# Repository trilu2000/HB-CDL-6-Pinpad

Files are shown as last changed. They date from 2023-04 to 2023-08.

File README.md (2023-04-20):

# HB-CDL-6-Pinpad
ein Pinpad zur Einbindung in Homematic

Im Gegensatz zum HB-CDL-6 (https://github.com/trilu2000/HB-CDL-6) mit Touchscreen habe ich diesmal versucht nur Standardbauteile zu verwenden um einen einfachen Nachbau zu gewährleisten.
Herausgekommen ist dabei das HB-CDL-6-Pinpad.

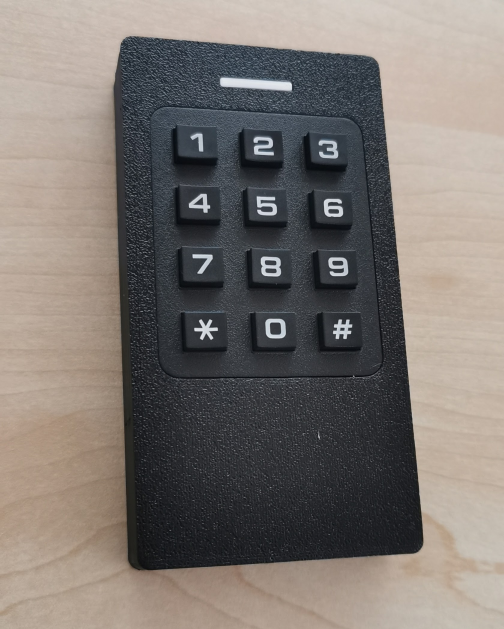
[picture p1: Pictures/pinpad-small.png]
Gerätebild


Grundsätzlich verhält sich das Gerät wie ein 6 Fach Wandtaster, nur das die Tasten durch einen Pincode ersetzt werden.
Über die CCU Oberfläche hat man die Möglichkeit 12 verschedene Pin's den jeweiligen Kanälen zuzuordnen.

Selbst das Anlernen des Geräts wird über die Pin-Tastatur gestartet.

## Bauteile für den Nachbau
* HMSensor-CR2032 ohne CR2032 Batteriehalter https://asksinpp.de/Projekte/psi/HMSensor/#hmsensor-cr2032
* 3x4 Keypad https://www.ebay.de/itm/322734499078
* Batteriefedern https://www.ebay.de/itm/134133246378
* Batterie Federplatte https://www.ebay.de/itm/134128858997
* Gedruckte Gehäuseteile (im STL Unterordner) 

## Funktionsweise
Das Gerät hat 6 Schaltkanäle und kann 12 Pins verwalten. Die Einzelnen Pins können einem oder mehreren Kanälen zugeordnet werden.
Die Pineingabe folgt diesem Muster:
```
<Kanal> * <PIN> #
```

Kanal kann 1 bis 6 sein, es lassen sich im Programmcode aber auch Sonderkanäle für diverse Aktionen einbauen.
Derzeit gibt es nur einen Sonderkanal:
```
20 * Master PIN # startet das Pairing.
```

Die PIN's können bis zu 8 Stellen lang sein. Es besteht auch die Möglichkeit Kanäle einem leeren PIN zuzuweisen.
Eine mögliche Anwendung wäre das Schliessen der Garage.
Dazu würde man dann folgendes Muster eintippen:
```
<Kanal> * #
<Kanal> #
```
  
Pin 0 ist definiert als Master PIN. Dieser PIN ist im Programmcode definiert als: 
```
const uint8_t master_pwd[9] = { 0xff,'1','2','3','4','5','6','7','8', };
```
Der Master PIN kann beim kompilieren oder später über die CCU Oberfläche geändert werden.

Da es sich um ein Homebrew Gerät handelt, braucht es Jérôme's addon zur Einbindung in die CCU.

 https://github.com/jp112sdl/JP-HB-Devices-addon

## Pinpad

Es gibt verschiedene Versionen des Pinpads mit unterschiedlichen Pinbelegungen.

 Das von mir verwendete hat folgendes Pinout:

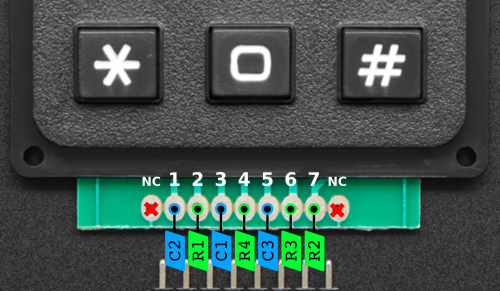
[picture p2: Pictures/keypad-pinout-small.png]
Keypad Pinout


Im Programmcode werden die Pins den Eingängen der HM Sensor Platine zugewiesen:
```
#define C2_PIN A0
#define R1_PIN A1
#define C1_PIN A2
#define R4_PIN A3
#define C3_PIN A4
#define R3_PIN A5
#define R2_PIN 3
```

## Bilder zum Aufbau

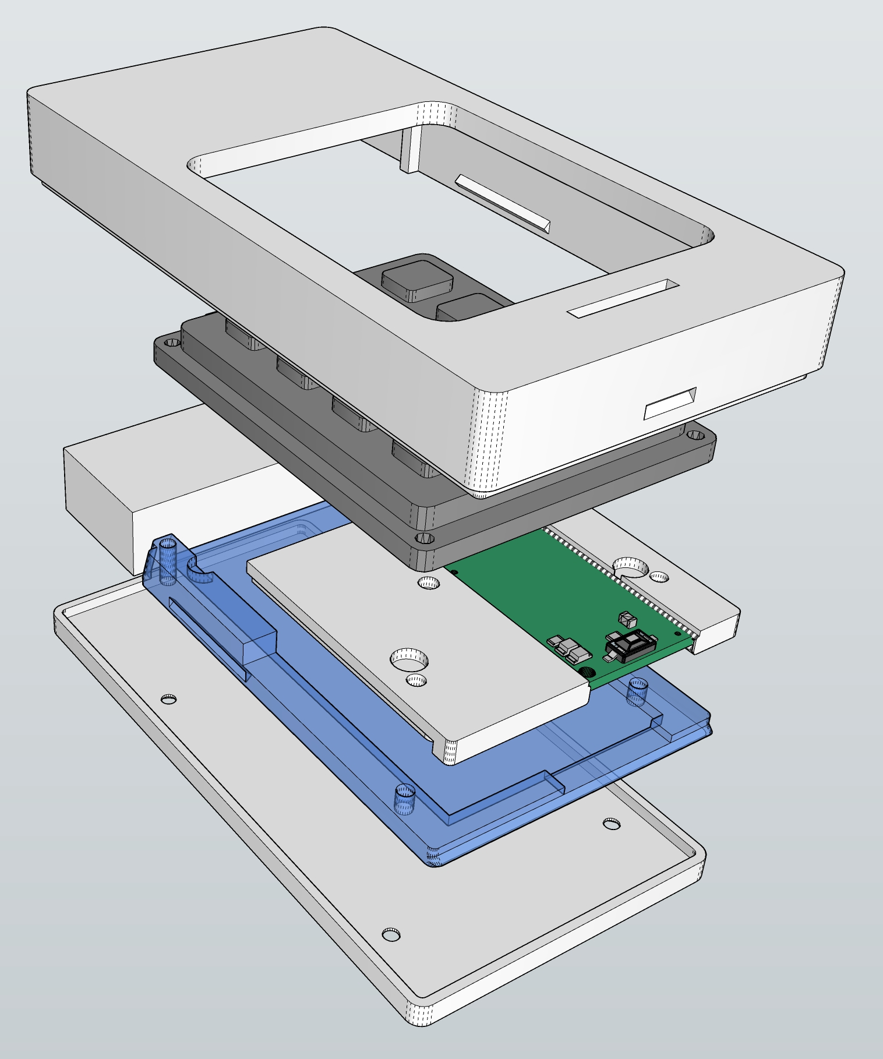
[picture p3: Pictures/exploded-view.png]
Pinpad exploded view


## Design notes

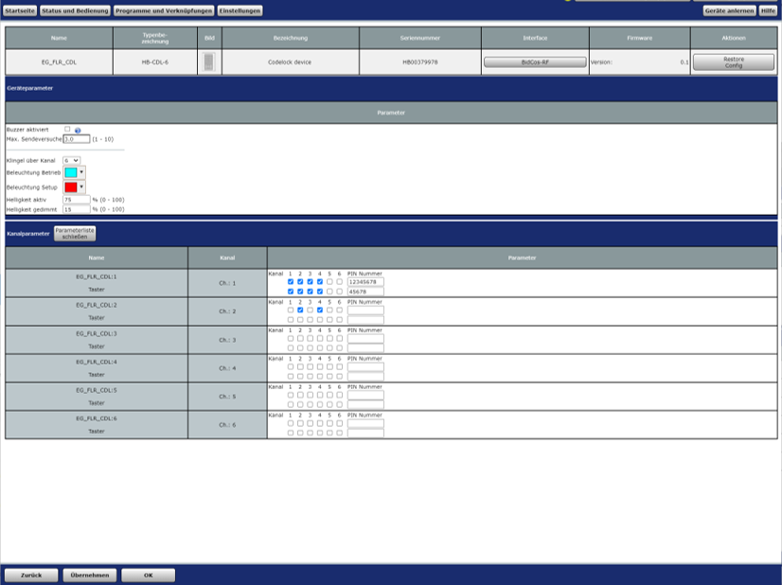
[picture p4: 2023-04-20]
Pictures/CCU.png

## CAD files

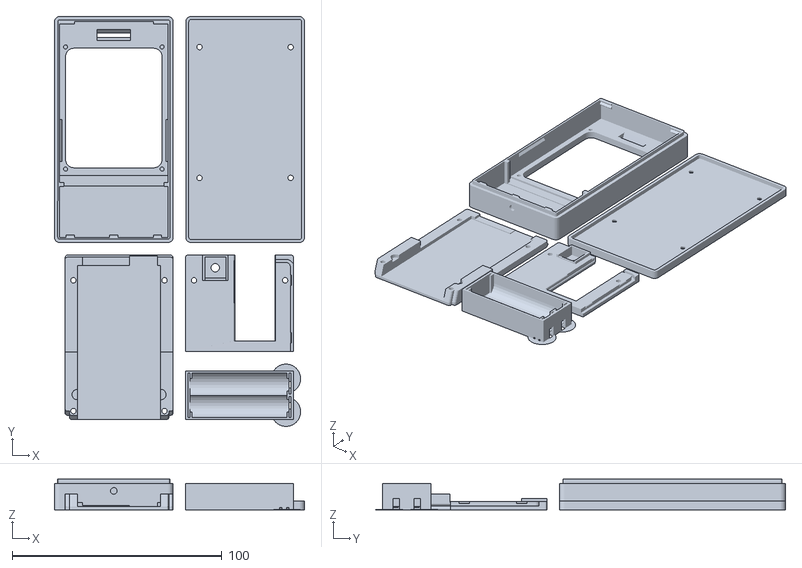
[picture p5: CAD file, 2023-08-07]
STL-files/Pinpad-case-complete.stl
119.2 x 195.3 x 14.6

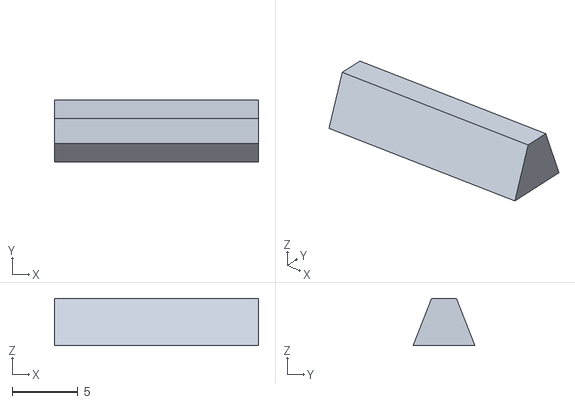
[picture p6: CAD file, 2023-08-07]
STL-files/Pinpad-led-difusor.stl
15.5 x 4.70 x 3.60

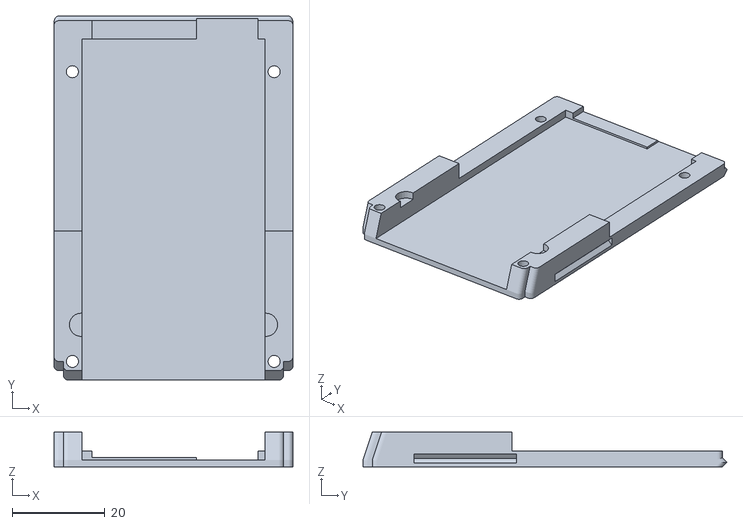
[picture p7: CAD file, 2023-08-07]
STL-files/Pinpad-internal-cover.stl
51.4 x 78.3 x 7.50

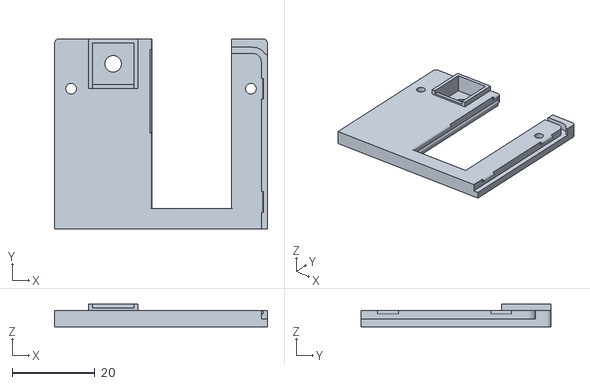
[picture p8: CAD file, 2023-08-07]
STL-files/Pinpad-pcb-holder.stl
51.4 x 45.9 x 5.51

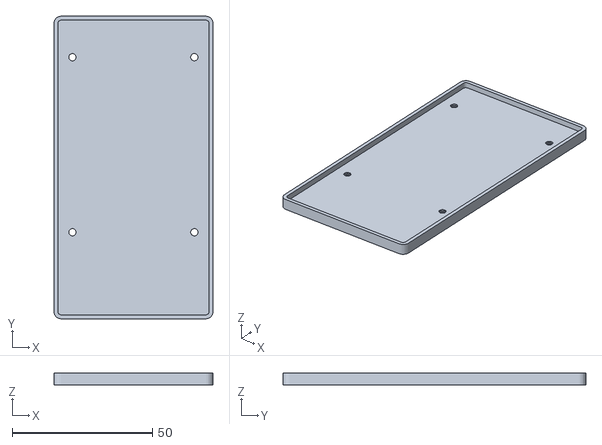
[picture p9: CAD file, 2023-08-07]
STL-files/Pinpad-case-bottom.stl
56.6 x 107.7 x 4.10

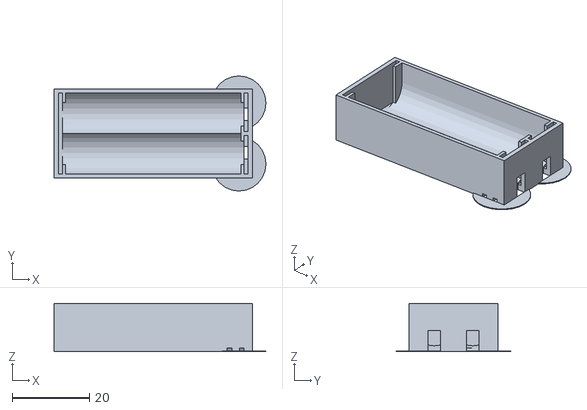
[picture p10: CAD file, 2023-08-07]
STL-files/Pinpad-battery-holder.stl
54.8 x 29.8 x 12.5

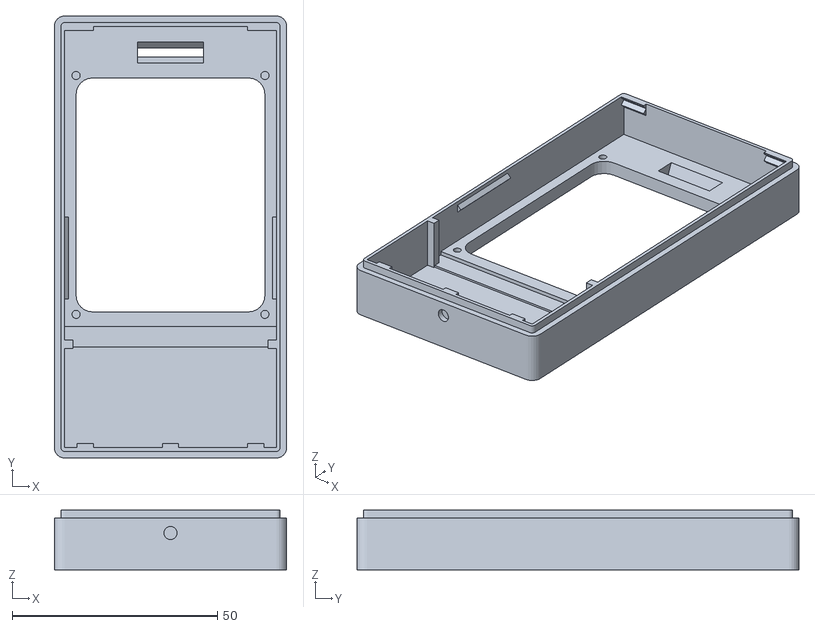
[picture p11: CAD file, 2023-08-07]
STL-files/Pinpad-case-top.stl
56.6 x 107.7 x 14.6

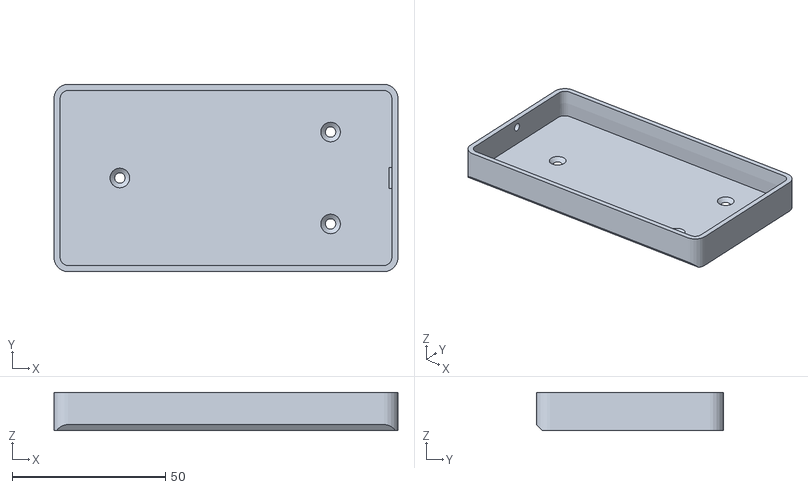
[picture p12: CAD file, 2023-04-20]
STL-files/Pinpad-holder.stl
112.3 x 61.2 x 12.5

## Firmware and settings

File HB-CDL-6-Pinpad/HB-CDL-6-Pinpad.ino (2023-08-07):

//- -----------------------------------------------------------------------------------------------------------------------
// AskSin++
// 2016-10-31 papa Creative Commons - http://creativecommons.org/licenses/by-nc-sa/3.0/de/
//- -----------------------------------------------------------------------------------------------------------------------

// define this to read the device id, serial and device type from bootloader section
// #define USE_OTA_BOOTLOADER
#include "key.h"
#define USE_AES   //0x01,0x02,0x03,0x04,0x05,0x06,0x07,0x08,0x09,0x0a,0x0b,0x0c,0x0d,0x0e,0x0f,0x10
#define HM_DEF_KEY_INDEX 0

#define HIDE_IGNORE_MSG

#define EI_NOTEXTERNAL
#include <EnableInterrupt.h>
#include <SPI.h>  // after including SPI Library - we can use LibSPI class
#include <LowPower.h>
#include <AskSinPP.h>
#include <Register.h>
#include <MultiChannelDevice.h>

#include "Pinpad.h"
#include "Backled.h"


#define LED1_PIN 5
#define LED2_PIN 4
#define CONFIG_BUTTON_PIN 8

// define only if a WS2812 led is implemented
//#define BACKLED_PIN 0
//#define NUMBER_LEDS 4

#define BUZZER_PIN 6

// define keyboard pins for a 3x4 Pinpad
#define C2_PIN A0
#define R1_PIN A1
#define C1_PIN A2
#define R4_PIN A3
#define C3_PIN A4
#define R3_PIN A5
#define R2_PIN 3


// - password master for codelock class ------------------------------
const uint8_t master_pwd[9] = { 0xff,'1','2','3','4','5','6','7','8', };

// number of available peers per channel
#define PEERS_PER_CHANNEL 10

// number of password slots
#define NR_CDL_CHANNELS 6



// all library classes are placed in the namespace 'as'
using namespace as;

// define all device properties
const struct DeviceInfo PROGMEM devinfo = {
	//{0x05, 0xcc, 0x55},     // Device ID
	//"HB00379910",           // Device Serial
	{0x05, 0xcc, 0x4a},   // Device ID
	"HB00379978",         // Device Serial
	{0xF6,0xA9},            // Device Model
  0x01,                   // Firmware Version
  as::DeviceType::PushButton, // Device Type
  {0x00,0x00}             // Info Bytes
};


/**
 * Configure the used hardware
 */
typedef AvrSPI<10, 11, 12, 13> SPIType;
typedef Radio<SPIType,2> RadioType;
typedef DualStatusLed<LED1_PIN, LED2_PIN> LedType;

typedef Buzzer<BUZZER_PIN> BuzzerType;
//typedef NoBuzzer BuzzerType;
//typedef AskSin<LedType, NoBattery, RadioType, BuzzerType > HalType;
typedef AskSin<LedType, BatterySensor, RadioType, BuzzerType > HalType;

typedef NoBackled<LedType> BackledType; 
//typedef Backled<BACKLED_PIN, NUMBER_LEDS> BackledType;



class Hal : public HalType {
public:
	void init (const HMID& id) {
		HalType::init(id);
		// measure battery every 1h
		battery.init(seconds2ticks(60UL * 60), sysclock);
		battery.low(22);
		battery.critical(19);
  }
  bool runready () {
		return HalType::runready() || sysclock.runready();
	}
} hal;


// - dfinition of Input device, can be either a mpr121 touch, or a 3x4 keypad
const uint8_t colPin[3] = { C1_PIN, C2_PIN, C3_PIN };
const uint8_t rowPin[4] = { R1_PIN, R2_PIN, R3_PIN, R4_PIN };
typedef Pinpad<colPin, rowPin> InputType;


// - List0 definition, needed for maintenance device -----------------
#define DREG_ACTIVE_COLOR 0x2E
#define DREG_PROGRAM_COLOR 0x2F
#define DREG_TOUCHED_BRIGHT 0x30
#define DREG_DIMMED_BRIGHT 0x31
#define DREG_RINGER_CHANNEL 0x32
DEFREGISTER(CDLReg0, MASTERID_REGS, DREG_TRANSMITTRYMAX, DREG_BUZZER_ENABLED, DREG_ACTIVE_COLOR, DREG_PROGRAM_COLOR, DREG_TOUCHED_BRIGHT, DREG_DIMMED_BRIGHT, DREG_RINGER_CHANNEL)
class CDLList0 : public RegList0<CDLReg0> {
public:
	CDLList0(uint16_t addr) :
		RegList0<CDLReg0>(addr) {
	}

	uint8_t activeColor() const { return this->readRegister(DREG_ACTIVE_COLOR, 0); }
	bool activeColor(uint8_t value) const { return writeRegister(DREG_ACTIVE_COLOR, value); }

	uint8_t programColor() const { return this->readRegister(DREG_PROGRAM_COLOR, 0); }
	bool programColor(uint8_t value) const { return writeRegister(DREG_PROGRAM_COLOR, value); }

	uint8_t touchedBright() const { return this->readRegister(DREG_TOUCHED_BRIGHT, 0); }
	bool touchedBright(uint8_t value) const { return writeRegister(DREG_TOUCHED_BRIGHT, value); }

	uint8_t dimmedBright() const { return this->readRegister(DREG_DIMMED_BRIGHT, 0); }
	bool dimmedBright(uint8_t value) const { return writeRegister(DREG_DIMMED_BRIGHT, value); }

	uint8_t ringerChannel() const { return this->readRegister(DREG_RINGER_CHANNEL, 0x07, 0, 0); }
	bool ringerChannel(uint8_t value) const { return writeRegister(DREG_RINGER_CHANNEL, 0x07, 0, value); }

	void defaults() {
		clear();
		buzzerEnabled(true);
		transmitDevTryMax(2);
		activeColor(100);
		programColor(0);
		touchedBright(150);
		dimmedBright(30); 
		ringerChannel(6);
	}
};

// - List1 definition, needed for all cdl channels -------------------
DEFREGISTER(CDLReg1, CREG_AES_ACTIVE, 0x36, 0x37, 0x38, 0x39, 0x3a, 0x3b, 0x3c, 0x3d, 0x3e, 0x3f, 0x40, 0x41, 0x42, 0x43, 0x44, 0x45, 0x46, 0x47, )
class CDLList1 : public RegList1<CDLReg1> {
public:
	CDLList1(uint16_t addr) : RegList1<CDLReg1>(addr) {}

	void byte_array(uint8_t slot, uint8_t* value) const {
		DPRINT(F("write: ")); DHEXLN(value, 9);
		uint8_t offset = 0x36 + (slot * 9);
		for (uint8_t i = 0; i < 9; i++) {
			this->writeRegister(offset + i, value[i] & 0xff);
		}
	}

	uint8_t* byte_array(uint8_t slot) const {
		static uint8_t temp_byte_array[9];
		uint8_t offset = 0x36 + (slot * 9);
		for (uint8_t i = 0; i < 9; i++) {
			temp_byte_array[i] = this->readRegister(offset + i);
		}
		//DPRINT("read:"); DHEXLN(temp_byte_array, 9);
		return temp_byte_array;
	}

	void defaults() {
		clear();
	}
};

// - channel definition, manage state() and first init ---------------
template<class HALTYPE, int PEERCOUNT, class List0Type, class List1Type>
class CDLChannel : public Channel<HALTYPE, List1Type, EmptyList, DefList4, PEERCOUNT, List0Type> {
	uint8_t repeatcnt;

public:
	typedef Channel<HALTYPE, List1Type, EmptyList, DefList4, PEERCOUNT, List0Type> BaseChannel;

	CDLChannel() : BaseChannel(), repeatcnt(0) {}
	virtual ~CDLChannel() {}

	uint8_t status() const { return 0; }
	uint8_t flags() const {	return 0; }
	bool configChanged() { return true; }

	void sendMsg() {
		DHEX(BaseChannel::number()); DPRINTLN(F(" released"));
		RemoteEventMsg& msg = (RemoteEventMsg&)this->device().message();
		msg.init(this->device().nextcount(), BaseChannel::number(), repeatcnt, 0, this->device().battery().low());
		this->device().sendPeerEvent(msg, *this);
		repeatcnt++;
	}

	void firstinit() {
		const uint8_t temp_byte_array[9] = { 0,0,0,0,0,0,0,0,0 };

		if (this->number() == 1) this->getList1().byte_array(0, master_pwd);
		else this->getList1().byte_array(0, temp_byte_array);
		this->getList1().byte_array(1, temp_byte_array);
	}
};

typedef CDLChannel<Hal, PEERS_PER_CHANNEL, CDLList0, CDLList1> CdlChannel;

// - device definition, registers all single channels ----------------
template <class HalType, class ChannelType, int ChannelCount, class List0Type, class BackledType>
class CDLChannelDevice : public ChannelDevice<HalType, ChannelType, ChannelCount, List0Type>, public InputType {
	ChannelType cdata[ChannelCount];
	BackledType backled;
	uint8_t ringer_channel;

	class Buffer {
		enum STATE {CNL = 0, PWD};
		STATE state;
		
		struct {
			uint8_t cnl;
			uint8_t cnt;
			uint8_t pwd[8];
		} store;

	public:
		Buffer() {}
		~Buffer() {}

		void add(uint8_t r) {	
			if (r == 0x0b) {						// * is the delimiter between cnl and password
				state = PWD;
			}
			else if (state == CNL) {		// all input into cnl
				store.cnl *= 10;					// previous figure is now *10
				store.cnl += r - 0x30;		// as we get ASCII input	
			}
			else if (state == PWD) {		// all input into pwd buffer
				if (store.cnt > 7) store.cnt = 7;
				store.pwd[store.cnt++] = r;
			}
		} 

		void clear() {								// clear all
			uint8_t cnt = 0;
			while (cnt < 10) ((uint8_t*)&store)[cnt++] = 0;
			state = CNL;
		}

		uint8_t channel()   {	return store.cnl;	}
		uint8_t length()    { return store.cnt; }
		uint8_t* password() { return store.pwd; }

	} buffer;

	class Timeout : public Alarm {
		CDLChannelDevice& cd;
	public:
		Timeout(CDLChannelDevice& d) : Alarm(0), cd(d) {}
		virtual ~Timeout() {}

		void start() {
			stop();
			set(seconds2ticks(5));
			sysclock.add(*this);
		}

		void stop() {
			sysclock.cancel(*this);
		}

		virtual void trigger(__attribute__((unused)) AlarmClock& clock) {
			// timeout arrived, clear buffer, beep and set backled
			DPRINTLN(F("timeout..."));
			cd.clear();
		}
	} timeout;

	uint8_t compare_array(uint8_t* in1, uint8_t* in2) {
		for (uint8_t i = 0; i < 8; i++) {
			if (in1[i] != in2[i]) return 0;
		}
		return 1;
	}

	uint8_t* get_array(uint8_t slot) {
		// we store 2 access/passwords per channel, we are numbering them by slots (channels * 2) to address them easier 
		uint8_t cnl = (slot / 2) + 1;	
		return channel(cnl).getList1().byte_array(slot & 0x01);
	}
	
	uint8_t validate_password(uint8_t* pwd) {
		uint8_t slots = this->channels() * 2;
		for (uint8_t i = 0; i < slots; i++) {
			uint8_t* p_slot = get_array(i);
			uint8_t comp = compare_array(p_slot + 1, pwd);		// slot_array(i) + 1, password starts with 2nd byte
			//DHEX(i); DPRINT(F(": ")); DHEXLN(p_slot, 9);
			if ((comp) && (p_slot[0])) return i;							// password must match and channelbyte cannot be empty
		}
		return 0xff;																				// ff means, nothing found
	}

	uint8_t validate_channel(uint8_t slot, uint8_t cnl) {
		uint8_t* p_slot = get_array(slot);
		uint8_t x = 1 << (cnl - 1);
		//DPRINT(F("slot:")); DHEX(p_slot[0]); DPRINT(F(",cnl:")); DHEX(cnl); DPRINT(F(",bit:")); DHEXLN(x);
		return (p_slot[0] & x)?cnl:0;
	}

public:
	CDLChannelDevice(const DeviceInfo& i, uint16_t addr) : ChannelDevice<HalType, ChannelType, ChannelCount, List0Type>(i, addr), timeout(*this) {
		for (uint8_t i = 0; i < ChannelCount; ++i) {
			this->registerChannel(cdata[i], i + 1);
		}
	}
	virtual ~CDLChannelDevice() {}

	void configChanged() {
		// config change via CCU, store settings in ram 
		ringer_channel = this->getList0().ringerChannel();
		buzzer().enabled(getList0().buzzerEnabled());
		backled.color[BACKLED::COLOR::OPERATE] = this->getList0().activeColor();
		backled.color[BACKLED::COLOR::PROGRAM] = this->getList0().programColor();
		backled.bright[BACKLED::BRIGHT::TOUCHED] = this->getList0().touchedBright();
		backled.bright[BACKLED::BRIGHT::DIMMED] = this->getList0().dimmedBright();
		backled.update();
	}

	bool init(HalType& hal) {
		// sdev.init(hal) calls this function, we are forwarding it to the multichanneldevice and inputtype device
		ChannelDevice<HalType, ChannelType, ChannelCount, List0Type>::init(hal);
		InputType::init();
		clear();
	}
	
	void clear() {
		timeout.stop();
		buffer.clear();
		backled.set_bright_mode(BACKLED::BRIGHT::DIMMED);
		backled.set_color_mode(BACKLED::COLOR::OPERATE);
	}

	virtual void keydown() {
		backled.set_bright_mode(BACKLED::BRIGHT::TOUCHED);											// flash light while key press
		buzzer().on(millis2ticks(70));
	}

	virtual void haskey(uint8_t k) {
		// function is called by the input device each time a keypress was recognised
		buzzer().off();
		backled.set_bright_mode(BACKLED::BRIGHT::DIMMED);												// dim the background ligh
		//DPRINT(F("key: 0x")); DHEXLN(k);

		timeout.start();

		if (k == 0x0c) {
			DPRINT(F("cnl: ")); DPRINT(buffer.channel()); DPRINT(F(", pwd: ")); DHEXLN(buffer.password(), 8);
			// check password and validate channel 
			uint8_t val_pwd = validate_password(buffer.password());
			if (val_pwd == 0xff) {
				clear();
				return;
			}
			uint8_t val_cnl = validate_channel(val_pwd, buffer.channel());
			DHEX(val_pwd); DPRINT(':'); DHEXLN(val_cnl);
			// we can define additional activities by defining special channels
			// channel 20 to send a pairing string
			// channel 99 to reprogram a slot
			if (val_cnl) channel(val_cnl).sendMsg();
			else if ((val_pwd == 0) && (buffer.channel() == 90)) startPairing();
			else if ((val_pwd == 0) && (buffer.channel() == 92)) reset();

			buzzer().on(millis2ticks(30), millis2ticks(50), 2);
			clear();
		}
		else {
			buffer.add(k);
		}
	}

};

typedef CDLChannelDevice<Hal, CdlChannel, NR_CDL_CHANNELS, CDLList0, BackledType> CodelockDevice;

// - creation of the homebrew device ---------------------------------
CodelockDevice  sdev(devinfo, 0x20);
ConfigButton<CodelockDevice> cfgBtn(sdev);
// - -----------------------------------------------------------------

void setup() {
  DINIT(57600,ASKSIN_PLUS_PLUS_IDENTIFIER);
	//storage().setByte(0, 0);
	sdev.init(hal);

  buttonISR(cfgBtn,CONFIG_BUTTON_PIN);
	sdev.initDone();
  DDEVINFO(sdev);

	sdev.buzzer().on(millis2ticks(100), millis2ticks(50), 2);
	//sdev.dumpSize();
}

void loop() {
	bool worked = hal.runready();
  bool poll = sdev.pollRadio();
  if( worked == false && poll == false ) {
		// if we drop below critical battery level - switch off all and sleep forever
		if (hal.battery.critical()) {
			// this call will never return
			hal.sleepForever();
		}
		//hal.activity.savePower<Sleep<>>(hal);
		hal.sleep<>();
	}

}

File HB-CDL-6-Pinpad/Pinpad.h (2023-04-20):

#ifndef _PINPAD_H
#define _PINPAD_H

using namespace as;

static void* __gb_pinpad;

template <const uint8_t *colPin, const uint8_t *rowPin>
class Pinpad {

	static Pinpad<colPin, rowPin>& instance() {
		return *((Pinpad< colPin, rowPin>*)__gb_pinpad);
	}

	static void isr() {
		instance().handle_int();
	}

	uint8_t read_row() {
		uint8_t ret = 0;
		for (uint8_t i = 0; i < 4; i++) {
			if (digitalRead(rowPin[i]) == 0)  ret = i + 1;
		}
		return ret;
	} 

	uint8_t read_col() {
		uint8_t ret = 0;
		for (uint8_t i = 0; i < 3; i++) {
			if (digitalRead(colPin[i]) == 0)  ret = i + 1;
		}
		return ret;
	} 

	void set_row_out_col_int() {
		for (uint8_t i = 0; i < 4; i++) {
			//DPRINT(rowPin[i]), DPRINT(',');
			pinMode(rowPin[i], OUTPUT);
			digitalWrite(rowPin[i], LOW);
		}
		for (uint8_t i = 0; i < 3; i++) {
			pinMode(colPin[i], INPUT_PULLUP);
			enableInterrupt(colPin[i], Pinpad::isr, FALLING);
		}
	}

	void set_col_out() {
		for (uint8_t i = 0; i < 3; i++) {
			disableInterrupt(colPin[i]);
			pinMode(colPin[i], OUTPUT);
			digitalWrite(colPin[i], LOW);
		}
		for (uint8_t i = 0; i < 4; i++) {
			pinMode(rowPin[i], INPUT_PULLUP);
		}
	}

	class Debounce : public Alarm {
		enum enum_state { IDLE = 0, WAIT, DEBOUNCE };
		volatile enum_state status;
		uint8_t key;
		Pinpad& pp;
	public:
		Debounce(Pinpad& p) : Alarm(0), pp(p), status(IDLE) {} 
		virtual ~Debounce() {}

		void start() {
			sysclock.cancel(*this);
			set(millis2ticks(50));
			status = WAIT;
			sysclock.add(*this);
		}

		enum_state state() {
			return status;
		}

		void create_key(uint8_t c, uint8_t r) {
			const uint8_t cor[] = { 0,0,3,6,9 };
			uint8_t ret = cor[r] + c;
			// swap *(10) and  0(11)
			if      (ret == 10) key = 0x0b;
			else if (ret == 11) key = 0x30;
			else if (ret == 12) key = 0x0c;
			else key = ret + 48;
		}

		virtual void trigger(AlarmClock& clock) {
			uint8_t ret = pp.read_row();
			if (!ret) { // not pressed, check if it was first time or debounce is done
				if (status == DEBOUNCE) {
					status = IDLE;
					pp.set_row_out_col_int();
					pp.haskey(key);
					return;
				}
				if (status == WAIT) {
					status = DEBOUNCE;
				}
			}
			// check again in 50 ms
			set(millis2ticks(50));
			sysclock.add(*this);
		}
	} debounce;

	
	void handle_int() {
		uint8_t col = 0, row = 0;

		// leave if debounce is working
		if (debounce.state()) return;
		// read the column and leave if nothing detected
		col = read_col();
		if (!col) return;
		// read the row and lave if empty
		set_col_out();
		row = read_row();
		if (!row) {
			set_row_out_col_int();
			return;
		}
		// calculate and store key code and wait for release/debounce
		debounce.create_key(col, row);
		debounce.start();
		keydown();
	}

public:
	Pinpad() : debounce(*this) {}
	~Pinpad() {}

	void init() {
		__gb_pinpad = this;
		DPRINTLN(F("keypad init"));
		set_row_out_col_int();
	}

	virtual void keydown() {
		DPRINTLN(F("keydown"));
	}
	virtual void haskey(uint8_t k) {
		DPRINT(F("key: 0x")); DHEXLN(k);
	}

};



#endif 

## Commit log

2023-04-20 initial upload
    [Pinpad-battery-holder.stl, Pinpad-case-bottom.stl, Pinpad-case-top.stl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]
2023-08-07 some maintenance updates
    [Pinpad-battery-holder.stl, Pinpad-case-bottom.stl, Pinpad-case-complete.stl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]
